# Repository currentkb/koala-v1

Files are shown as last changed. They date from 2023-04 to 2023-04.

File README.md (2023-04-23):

# koala keyboard

This is a 34-key column-staggered unibody keyboard.

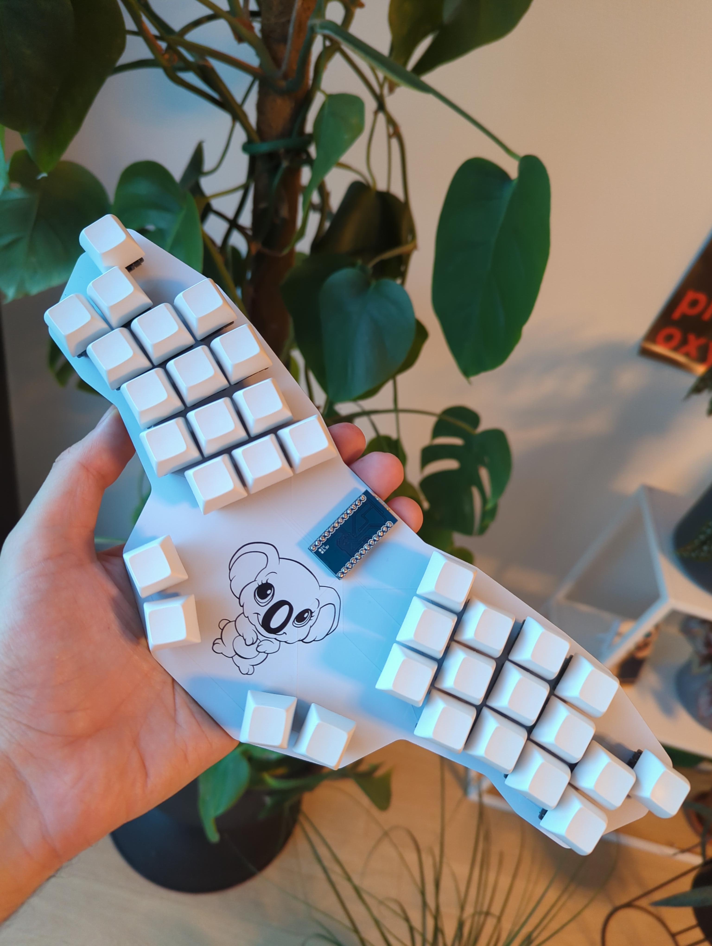
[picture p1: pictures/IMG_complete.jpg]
complete_build


## PCB

You can modify the [KiCad files](/kicad/) or straight download the [Gerber files](/gerber/) to order the PCB.

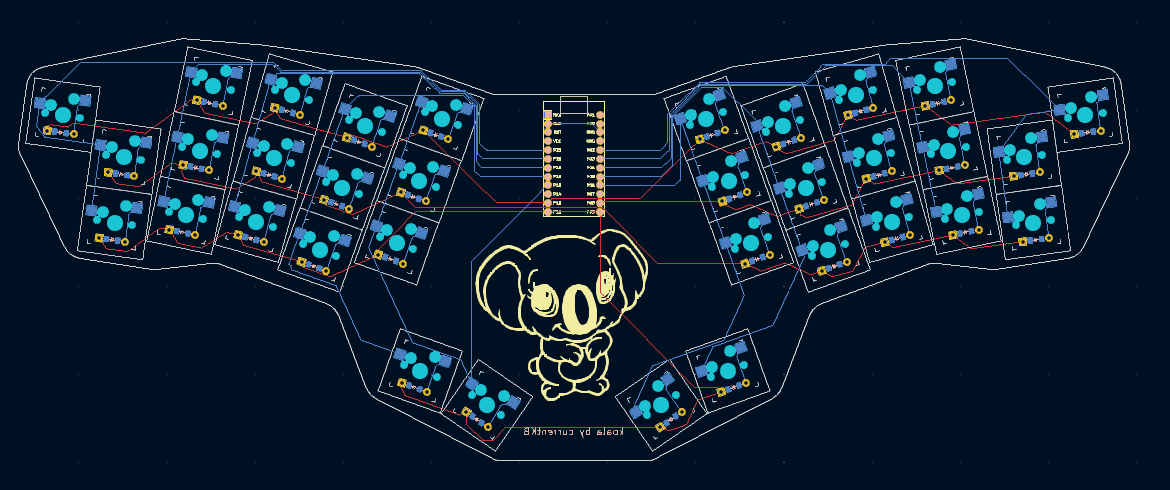
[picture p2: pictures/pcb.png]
pcb


## BUILD GUIDE
  
The build guide for the koala can be found [here](/docs/buildguide.md).
## Firmware

### QWERTY
      ┌───┬───┬───┬───┬───┐   ┌───┬───┬───┬───┬───┐
      │ Q │ W │ E │ R │ T │   │ Y │ U │ I │ O │ P │
      ├───┼───┼───┼───┼───│   │───┼───┼───┼───┼───┤
      │ A │ S │ D │ F │ G │   │ H │ J │ K │ L │ ; │
      ├───┼───┼───┼───┼───│   │───┼───┼───┼───┼───┤
      │ Z │ X │ C │ V │ B │   │ N │ M │ , │ . │ / │
      └───┴───┴───┼───┼───│   │───┼───┼───┴───┴───┘
                  │Ent│Tab│   │Bsp│Spc│
                  └───┴───┘   └───┴───┘
[QMK config: QWERTY](https://github.com/currentkb/qmk_firmware/tree/feat/koala/keyboards/koala/keymaps/default)

[pre-built firmware: QWERTY](/firmware/koala_default.hex)
### COLEMAK DH
    
      ┌───┬───┬───┬───┬───┐   ┌───┬───┬───┬───┬───┐
      │ Q │ W │ F │ P │ B │   │ J │ L │ U │ Y │ ; │
      ├───┼───┼───┼───┼───│   │───┼───┼───┼───┼───┤
      │ A │ R │ S │ T │ G │   │ M │ N │ E │ I │ O │
      ├───┼───┼───┼───┼───│   │───┼───┼───┼───┼───┤
      │ Z │ X │ C │ D │ V │   │ K │ H │ , │ . │ / │
      └───┴───┴───┼───┼───│   │───┼───┼───┴───┴───┘
                  │Ent│Tab│   │Bsp│Spc│
                  └───┴───┘   └───┴───┘

[QMK config: COLEMAK DH](https://github.com/currentkb/qmk_firmware/tree/feat/koala/keyboards/koala/keymaps/colemakdh)

[pre-built firmware: COLEMAK DH](/firmware/koala_colemakdh.hex)

## CREDITS

### INSPIRATION

The keyboard is inspired by the [clog-v4 keyboard from smores](https://github.com/smores56/clog-v4).

[Sam Mohr](https://github.com/smores56)

### PROCESS

The keyboard was built with the use of the [tutorial of FlatFootFox](https://flatfootfox.com/ergogen-introduction/).

[FlatFootFox](https://flatfootfox.com/)

### DOCUMENTATION

I used the [repository of the TOTEM keyboard](https://github.com/GEIGEIGEIST/TOTEM) as a reference to build this.

[GEIST](https://github.com/GEIGEIGEIST)

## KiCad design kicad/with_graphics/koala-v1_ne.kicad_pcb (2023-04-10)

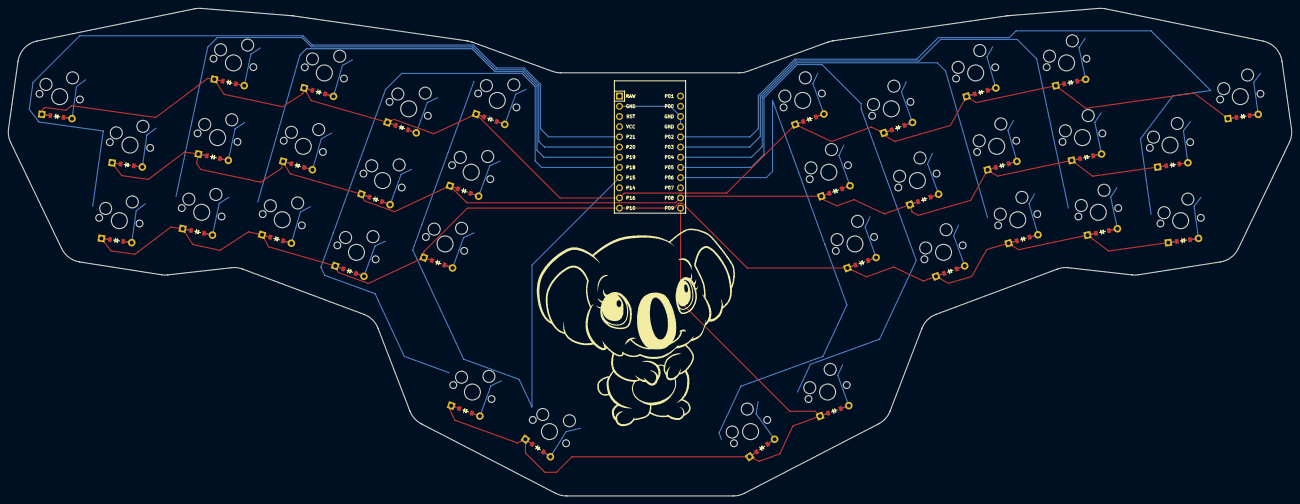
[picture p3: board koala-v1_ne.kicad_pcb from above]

Board: 2 copper layers, 320.2 x 121.7 mm, 69 parts (0 on the bottom side), 49 nets.

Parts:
D1, D2, D3, D4, D5, D6, D7, D8, D9, D10, D11, D12, D13, D14, D15, D16, D17, D18, D19, D20, D21, D22, D23, D24, D25, D26, D27, D28, D29, D30, D31, D32, D33, D34: ComboDiode
MCU1: ProMicro
S1, S2, S3, S4, S5, S6, S7, S8, S9, S10, S11, S12, S13, S14, S15, S16, S17, S18, S19, S20, S21, S22, S23, S24, S25, S26, S27, S28, S29, S30, S31, S32, S33, S34: MX

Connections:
GND: MCU1.2, MCU1.15, MCU1.16
P2: MCU1.17, S18.1, S19.1, S20.1
P3: MCU1.18, S21.1, S22.1, S23.1
P4: MCU1.19, S24.1, S25.1, S26.1
P5: MCU1.20, S27.1, S28.1, S29.1, S33.1
P6: MCU1.21, S30.1, S31.1, S32.1, S34.1
P8: D2.1, D5.1, D8.1, D11.1, D14.1, D19.1, D22.1, D25.1, D28.1, D31.1, MCU1.23
P9: D16.1, D17.1, D33.1, D34.1, MCU1.24
P10: D1.1, D4.1, D7.1, D10.1, D13.1, D18.1, D21.1, D24.1, D27.1, D30.1, MCU1.12
P15: MCU1.9, S13.1, S14.1, S15.1, S17.1
P16: D3.1, D6.1, D9.1, D12.1, D15.1, D20.1, D23.1, D26.1, D29.1, D32.1, MCU1.11
P18: MCU1.8, S10.1, S11.1, S12.1, S16.1
P19: MCU1.7, S7.1, S8.1, S9.1
P20: MCU1.6, S4.1, S5.1, S6.1
P21: MCU1.5, S1.1, S2.1, S3.1
index_bottom: D10.2, S10.2
index_home: D11.2, S11.2
index_top: D12.2, S12.2
inner_bottom: D13.2, S13.2
inner_cluster: D16.2, S16.2
inner_home: D14.2, S14.2
inner_top: D15.2, S15.2
middle_bottom: D7.2, S7.2
middle_home: D8.2, S8.2
middle_top: D9.2, S9.2
mirror_index_bottom: D27.2, S27.2
mirror_index_home: D28.2, S28.2
mirror_index_top: D29.2, S29.2
mirror_inner_bottom: D30.2, S30.2
mirror_inner_cluster: D33.2, S33.2
mirror_inner_home: D31.2, S31.2
mirror_inner_top: D32.2, S32.2
mirror_middle_bottom: D24.2, S24.2
mirror_middle_home: D25.2, S25.2
mirror_middle_top: D26.2, S26.2
mirror_outer_cluster: D34.2, S34.2
mirror_pinky_bottom: D18.2, S18.2
mirror_pinky_home: D19.2, S19.2
mirror_pinky_top: D20.2, S20.2
mirror_ring_bottom: D21.2, S21.2
mirror_ring_home: D22.2, S22.2
mirror_ring_top: D23.2, S23.2
outer_cluster: D17.2, S17.2
pinky_bottom: D1.2, S1.2
pinky_home: D2.2, S2.2
pinky_top: D3.2, S3.2
ring_bottom: D4.2, S4.2
ring_home: D5.2, S5.2
ring_top: D6.2, S6.2

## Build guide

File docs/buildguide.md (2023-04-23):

# KOALA BUILD GUIDE

## PART LIST
| Part name | Count | Remarks | 
| :--- | :---: | :--- |
| koala PCB | 01 | You can find the files for it [here](/gerber/) |
| Pro Micro | 01 |  |
| 12-Pin Sockets  | 02 |  |
| Mill-Max Pins | 24 | optional |
| MX key switch | 34 |  |
| MX hot-swap sockets | 34 |  |
| diodes 1N4148W  | 34 | You can use surface mount or through hole diodes |
| 1u MX keycaps | 34 | |
| USB cable | 01 | For connecting the keyboard with your PC. USB-C or Micro-USB cable - depends on the pro micro you use |

## DIODES

The diodes needs to be soldered on the bottom of the PCB. Pay attention to their orientation:  They have a small line on one side, which should be on the side the arrow on the PCB is facing to.

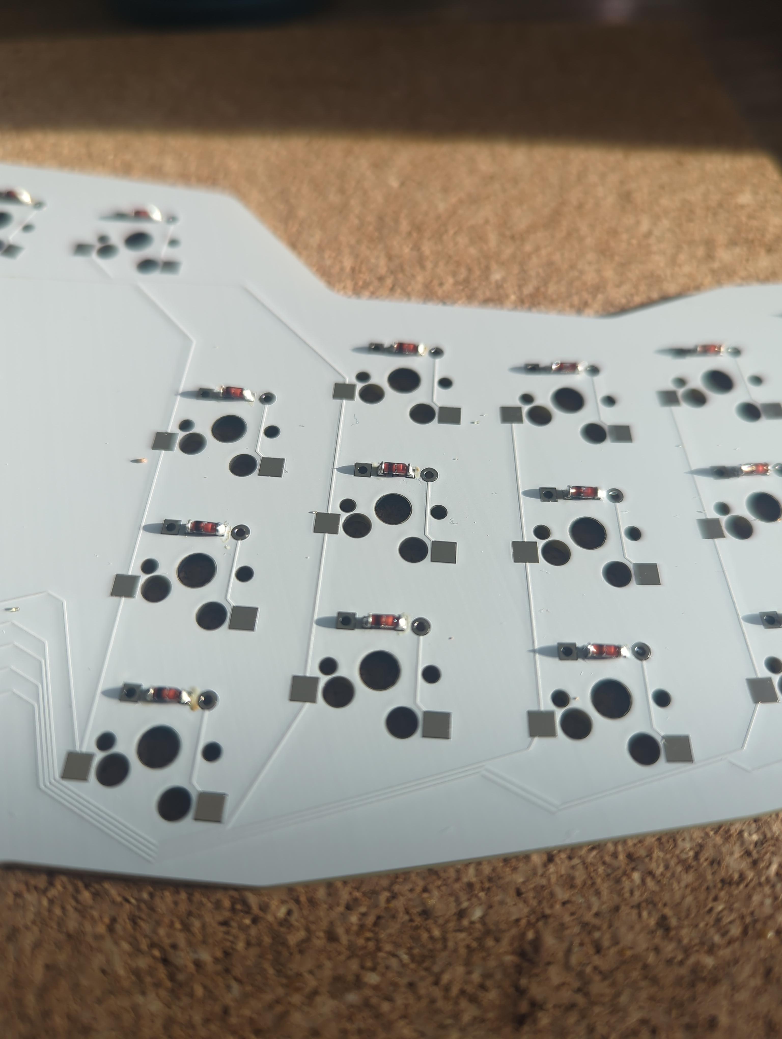
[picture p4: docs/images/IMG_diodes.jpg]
diodes


## HOT-SWAP SOCKETS

The hot-swap sockets have to be soldered also on the bottom of the PCB.

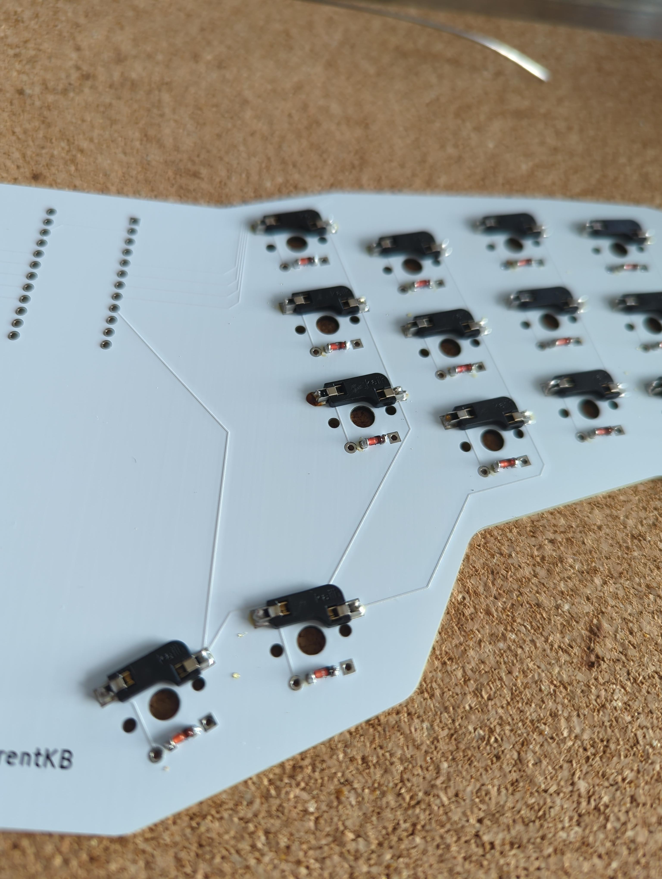
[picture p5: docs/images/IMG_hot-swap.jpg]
hot-swap


## MCU

Solder the 12-pin sockets for the MCU.

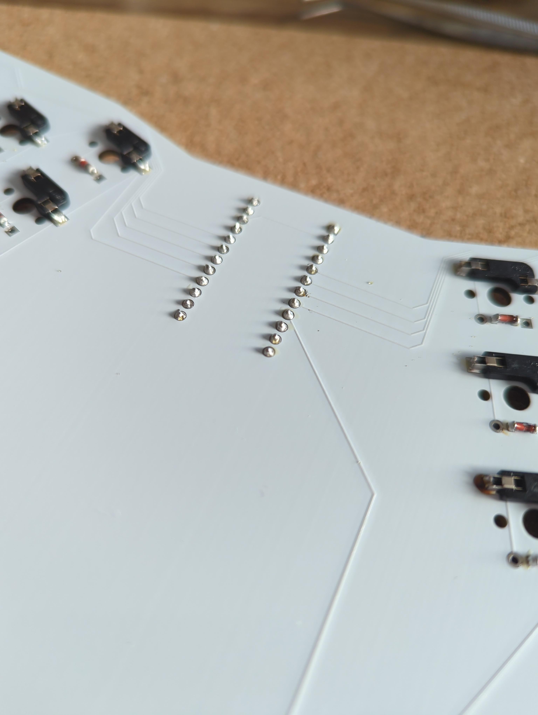
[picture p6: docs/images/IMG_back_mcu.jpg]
pin-sockets


Turn around the PCB and solder the MCU onto the sockets. Make sure to solder the MCU top down. Optionally use Mill-Max pins to make the MCU swappable.

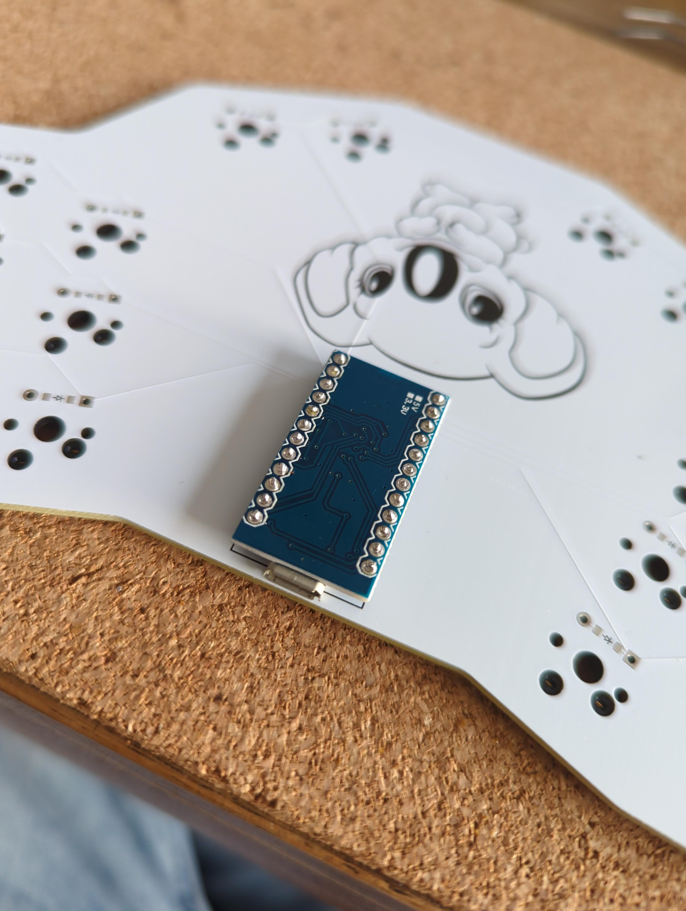
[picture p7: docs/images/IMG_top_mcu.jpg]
mcu


## CLEANING

You can use an old toothbrush and some isopropanol to clean it from residues.

## SWITCHES

Add your desired switches onto the board.

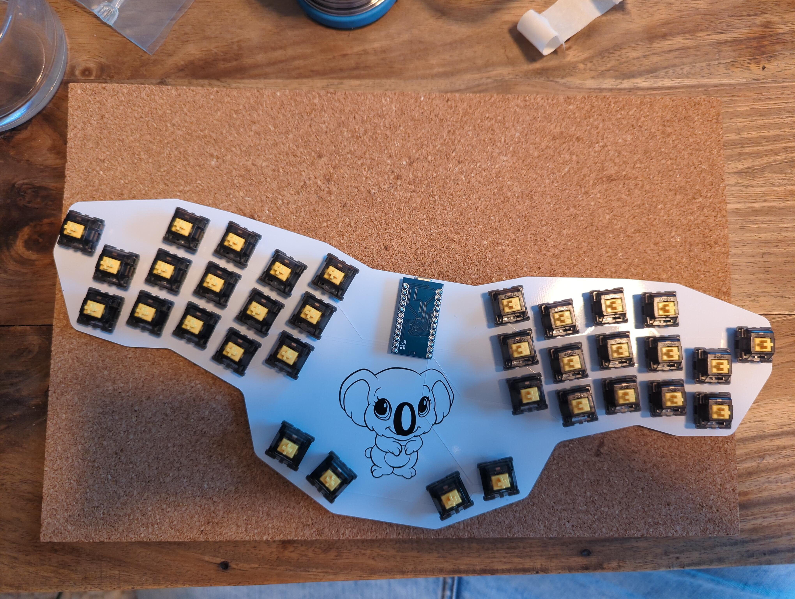
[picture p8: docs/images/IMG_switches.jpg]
switches


## FIRMWARE

If you have not already flashed the firmware to the microcontroller you should do it now.\
You can use the pre-built firmware for a [QWERTY layout](/firmware/koala_default.hex) or a [COLEMAK-DH layout](/firmware/koala_colemakdh.hex) or [modify and build your own QMK firmware](https://github.com/currentkb/qmk_firmware/tree/feat/koala/keyboards/koala).

After flashing the firmware, [make sure that every key is working](https://www.keyboardtester.com/).

## KEYCAPS

Finally, add some keycaps and happy typing.

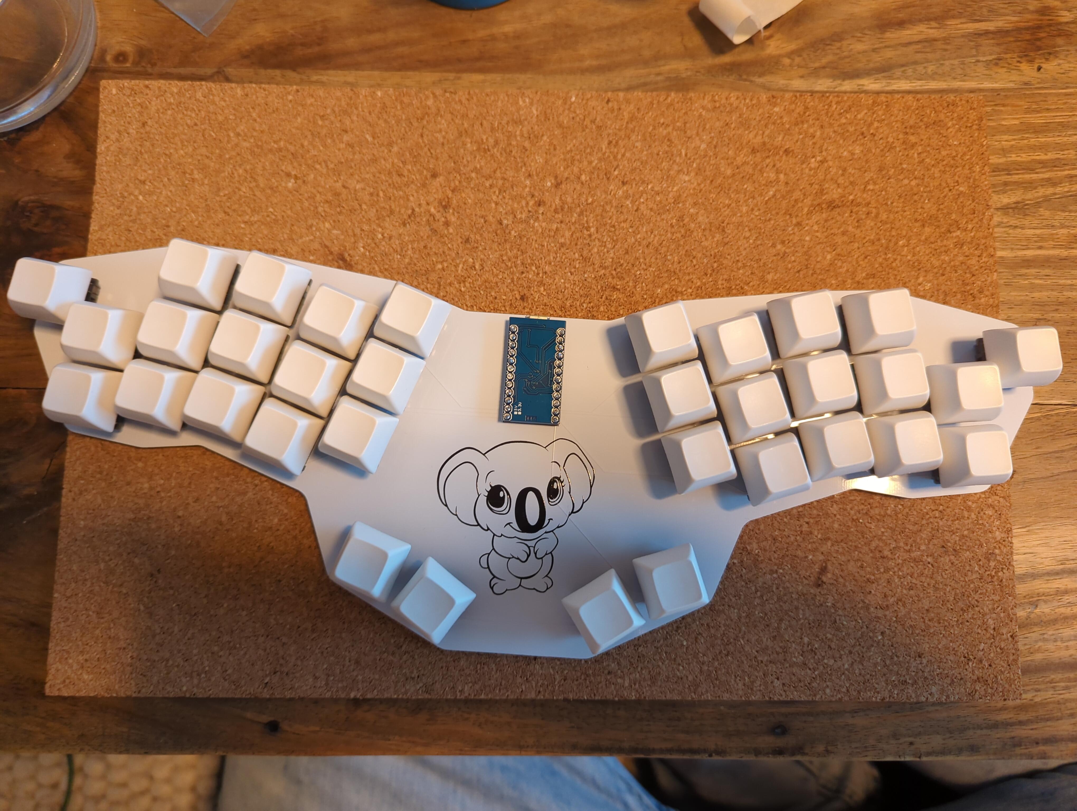
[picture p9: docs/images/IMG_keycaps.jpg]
keycaps


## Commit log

2023-04-10 feat(): initial commit
    [koala-v1.kicad_pcb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]
2023-04-10 chore(): add drill files and update production
    [koala-v1_ne.kicad_pcb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]
